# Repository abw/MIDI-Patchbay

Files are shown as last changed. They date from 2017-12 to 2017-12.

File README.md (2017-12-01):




# MIDI-Patchbay
This project contains hardware and firmware for a 4x4 MIDI
merger/splitter patchbay based on an Arduino MEGA 2560.
It has 4 MIDI inputs and 4 MIDI outputs.  In the
simplest case, it will merge all 4 inputs and then split the combined
MIDI stream across the 4 outputs.  However the routing is controlled by
the firmware so you can configure it to patch any combination of inputs
into any of the outputs.

# Table of contents
* [Hardware](#hardware)
* [Firmware](#firmware)
* [Warning](#warning)

## Hardware:

The [hardware](hardware)
directory contains Eagle schematics, board designs and Gerber files for
the following modules.

* [MIDI-Patchbay-Shield](hardware/MIDI-Patchbay-Shield)
is a shield for an Arduino MEGA 2560 that provides 4 MIDI inputs, 4 MIDI
outputs and connectors for interfacing to the
[MIDI-Patchbay-Display](hardware/MIDI-Patchbay-Display)
board.  It also contains connectors for accessing 8 analog pins and 8
digital pins for further expansion.  This is the main board that you
need to build.

* [MIDI-Patchbay-Display](hardware/MIDI-Patchbay-Display)
is a board for mounting a 16x2 LCD display and two RGB rotary encoders.
This is an optional extra.  You can build a fully functioning MIDI
merger/splitter without it.

* [MIDI-Patchbay-Simple](hardware/MIDI-Patchbay-Simple)
is the predecessor of the [MIDI-Patchbay-Shield](hardware/MIDI-Patchbay-Shield).
This is a reduced size shield for the Arduino MEGA 2560 that only has 4
MIDI inputs and 4 MIDI outputs, along with the relevant circuitry to
support it.  If you just want a simple MIDI merger/splitter without any
extra frills then this is the simplest option as an *alternative* to the
above.

The boards use surface mount (SMD) components, but nothing smaller than
0805 (that's 2012 in metric: approximately 2.0mm x 1.25mm) which can easily
be soldered by hand.  It's really not much harder than through-hole
components, so don't be put off if you haven't used SMD before.  But you
will need to invest in some tweezers and a magnifier/light unit to help
you see what you're doing.  And of course, a decent soldering iron.

## Firmware:

The [firmware](firmware)
directory contains the source code for the firmware that powers the
boards listed above.  It is built around the Arduino [MIDI Library](https://github.com/FortySevenEffects/arduino_midi_library)
by [Forty Seven Effects](https://github.com/FortySevenEffects).

* [MIDI-Patchbay-Simple.ino](firmware/MIDI-Patchbay-Simple.ino) implements
a simple 4x4 MIDI patchbay that merges all four MIDI inputs and duplicates
them across all four MIDI outputs.  It is specifically for use with the
basic [MIDI-Patchbay-Simple](hardware/MIDI-Patchbay-Simple) board, but
can also be used with the more advanced [MIDI-Patchbay-Shield](hardware/MIDI-Patchbay-Shield)
if you just need simple functionality.  Or you can use this as a starting
point for your own implementation of the firmware.

## Warning:

These are new designs that haven't been fully tested yet.  Use them at
your own risk.

## Author

Andy Wardley <abw@wardley.org> December 2017

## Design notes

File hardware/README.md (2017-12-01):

# Hardware

This directory contains the schematics and circuit board layouts for

* [MIDI-Patchbay-Shield](MIDI-Patchbay-Shield) adds MIDI IN/OUT
functionality to an Arduino MEGA 2560, along with connectors for
the optional [MIDI-Patchbay-Display](MIDI-Patchbay-Display) and
access to digital and analog pins for adding further switches,
potentiometers, etc.

* [MIDI-Patchbay-Display](MIDI-Patchbay-Display) is an optional extra
for mounting an LCD display and rotary encoders.  This is used in
conjunction with the [MIDI-Patchbay-Shield](MIDI-Patchbay-Shield).

* [MIDI-Patchbay-Simple](MIDI-Patchbay-Simple) is the predecessor to
[MIDI-Patchbay-Shield](MIDI-Patchbay-Shield).  It's an older and slightly
simpler version (e.g. no support for displays or rotary encoders), so
good if you just want a basic MIDI merger/splitter unit, or perhaps
something to adapt for your own project.

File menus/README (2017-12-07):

This directory is being used to develop and test a menu system for the LCD.

It uses a regular desktop development environment rather than targetting 
the Arduino.  This makes developing, testing and debugging considerably
easier. 

When it's nearing completion the code will be moved/merged into the 
formware/MIDI-Patchbay directory.

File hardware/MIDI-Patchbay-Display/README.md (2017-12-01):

# MIDI-Patchbay-Display

This directory contains the schematic and board layout for a daughter
board for mounting a 16x2 LCD display and 2 [RGB rotary encoders](https://www.sparkfun.com/products/10982).

This is an optional extra that can be used in conjunction with the
[MIDI-Patchbay-Shield](../MIDI-Patchbay-Shield)
or with your own projects that require an LCD display and/or encoders.

A 10 pin (2x5) IDC connector is used to connect to the LCD.  A 16 pin
(2x8) IDC connector is used to connect to the rotary encoders.

The board contains the "anti-chatter" circuits on the rotaty encoders that
are recommended in the [data sheet](https://cdn.sparkfun.com/datasheets/Components/Switches/EC12PLRGBSDVBF-D-25K-24-24C-6108-6HSPEC.pdf).
It also has a pull-down resistor, current limiting resistor and debounce
capacitor on the push switches for each encoder.

The RGB LEDs in the encoders, and the LED in the backlight of the LCD,
are all switched through transistors with the appropriate
current-limiting resistors in series.  The intensity of the LEDs can
be changed using Pulse Width Modulation (PWM) directly from Arduino
pins.  The transistors are used so that we're not powering the LEDs
directly from the Arduino pins and don't have to worry about exceeding
any of the current source/sink limits of the microprocessor.

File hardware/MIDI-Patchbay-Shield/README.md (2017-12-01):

# MIDI-Patchbay-Shield

This directory contains the schematic and board layout for the MIDI
Patchbay shield for the Arduino MEGA 2560.

This is the main circuit board that you need for the project.

It has connectors for 4 MIDI inputs and 4 MIDI outputs.

It has LCD and ENCODER connectors which you can use to connect it to the
[MIDI-Patchbay-Display](../MIDI-Patchbay-Display)
board.  This is an optional extra for attaching an LCD display and one or
two rotary encoders.  This allows you to monitor MIDI traffic, program and
select patches to change the MIDI routing, and generally interface with
the MIDI Patchbay.  It's not required if you just want to build a simple,
static MIDI merger/splitter.

Is has further DIGITAL and ANALOG connectors which give you easy
access to 8 digital pins and 8 analog pins.  You can use these for
expanding the project, e.g. to add push buttons or potentiometers.

There's also a PEDAL connector.  This is wired in parallel with MIDI
INPUT 1 but has an additional pin providing VIN voltage.  This is used
to connect to another project of mine, the MIDI Foot Pedal Controller
(coming to github soon).  You can ignore this for now.

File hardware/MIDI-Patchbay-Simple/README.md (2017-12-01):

# MIDI-Patchbay-Simple

This directory contains the schematic and board layout for the
predecessor/prototype of the [MIDI Patchbay Shield](../MIDI-Patchbay-Shield) for the Arduino MEGA 2560.

This is a simple 4 MIDI IN / 4 MIDI OUT merger and splitter.

The [MIDI Patchbay Shield](../MIDI-Patchbay-Shield)
is the newer design with more functionality, but if you want something
simple and slightly easier/cheaper/quicker to build then this might be
the droids you're looking for.

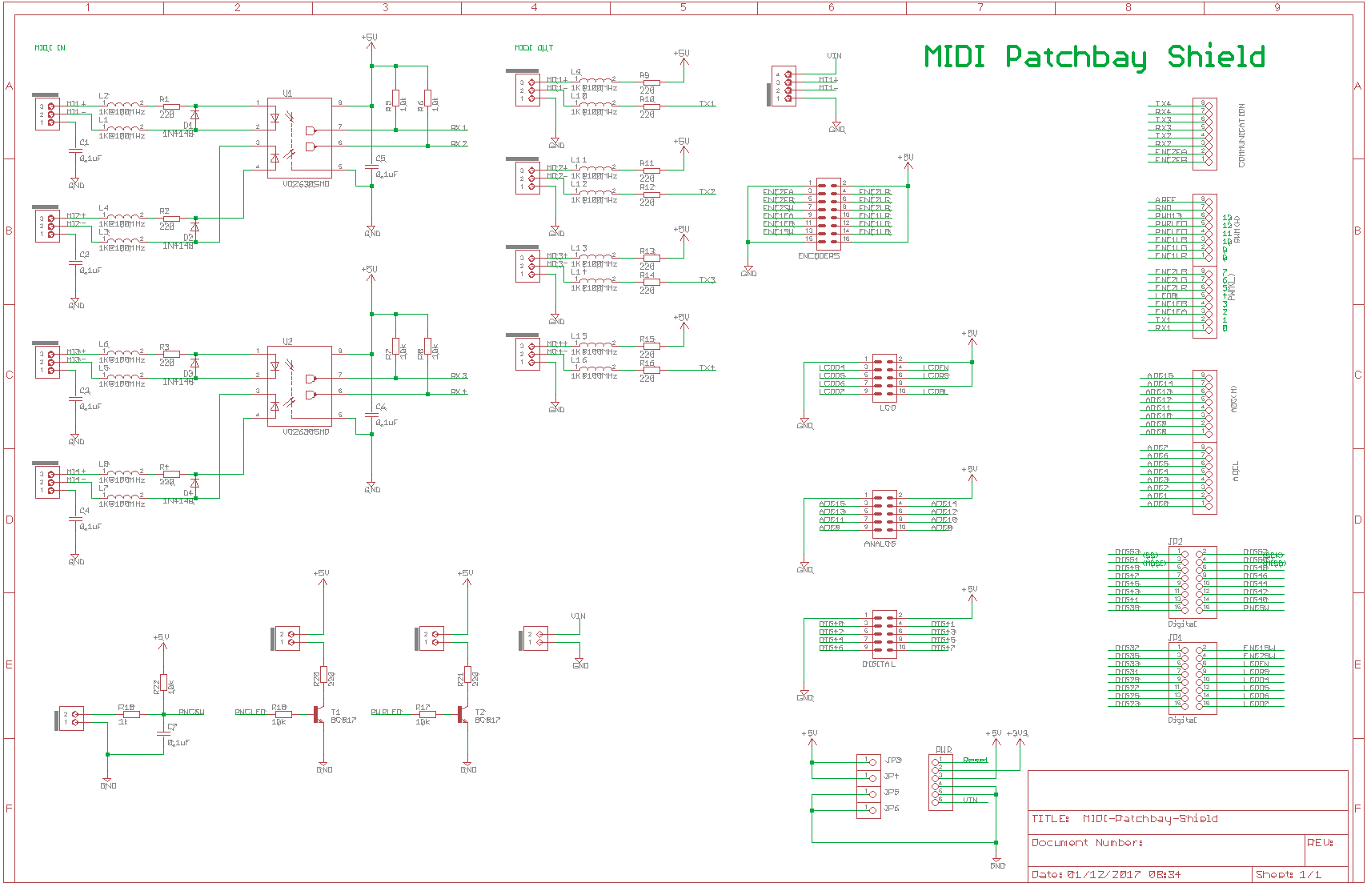
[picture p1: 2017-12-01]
hardware/MIDI-Patchbay-Shield/schematic.gif

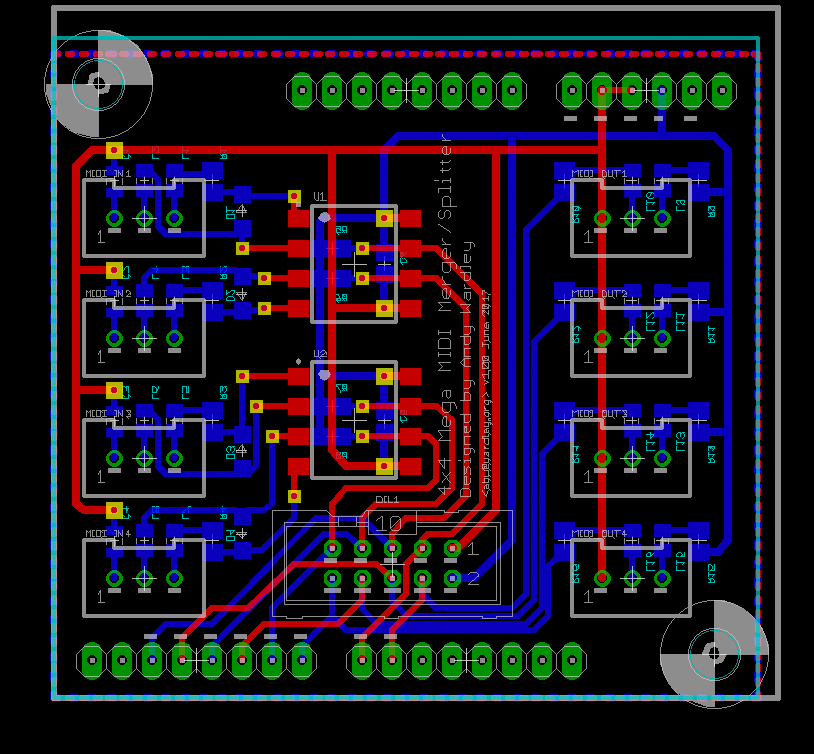
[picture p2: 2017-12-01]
hardware/MIDI-Patchbay-Simple/board.gif

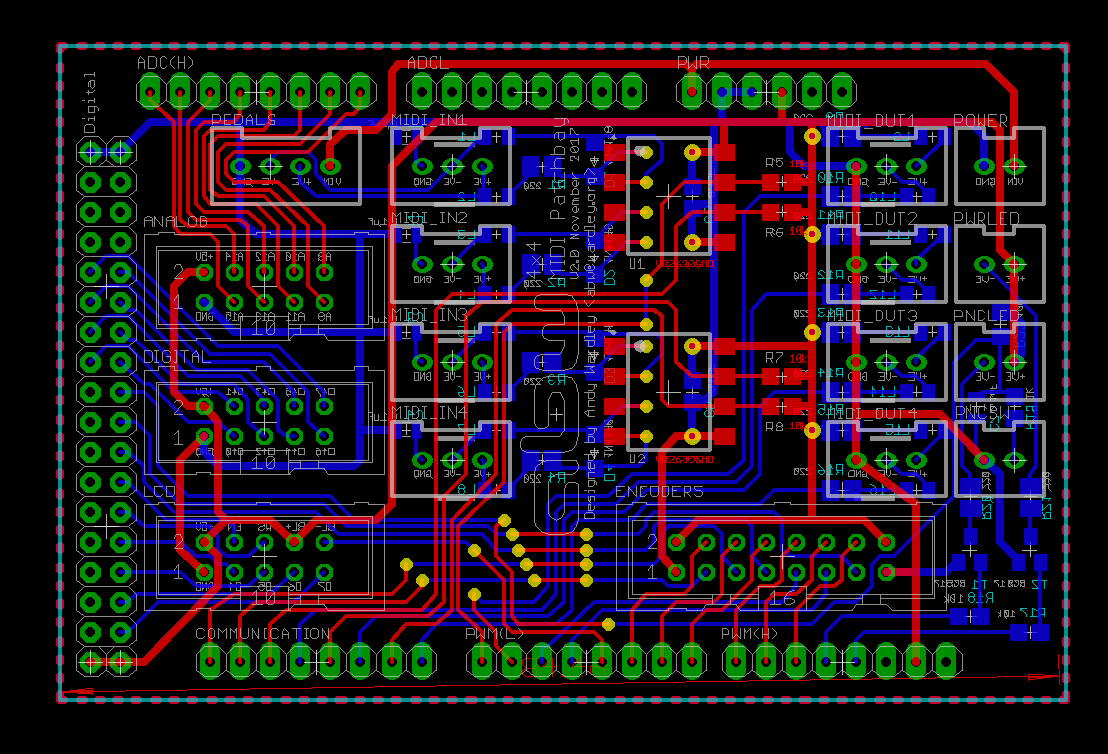
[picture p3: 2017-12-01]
hardware/MIDI-Patchbay-Shield/board.gif

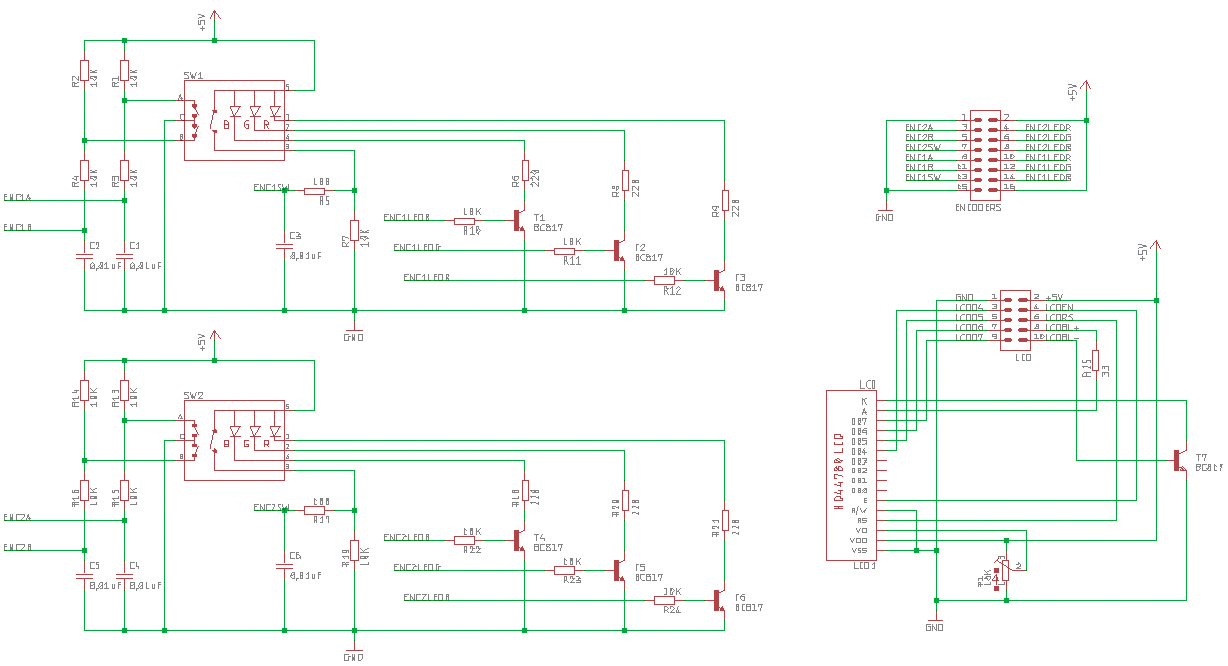
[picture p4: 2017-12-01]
hardware/MIDI-Patchbay-Display/schematic.gif

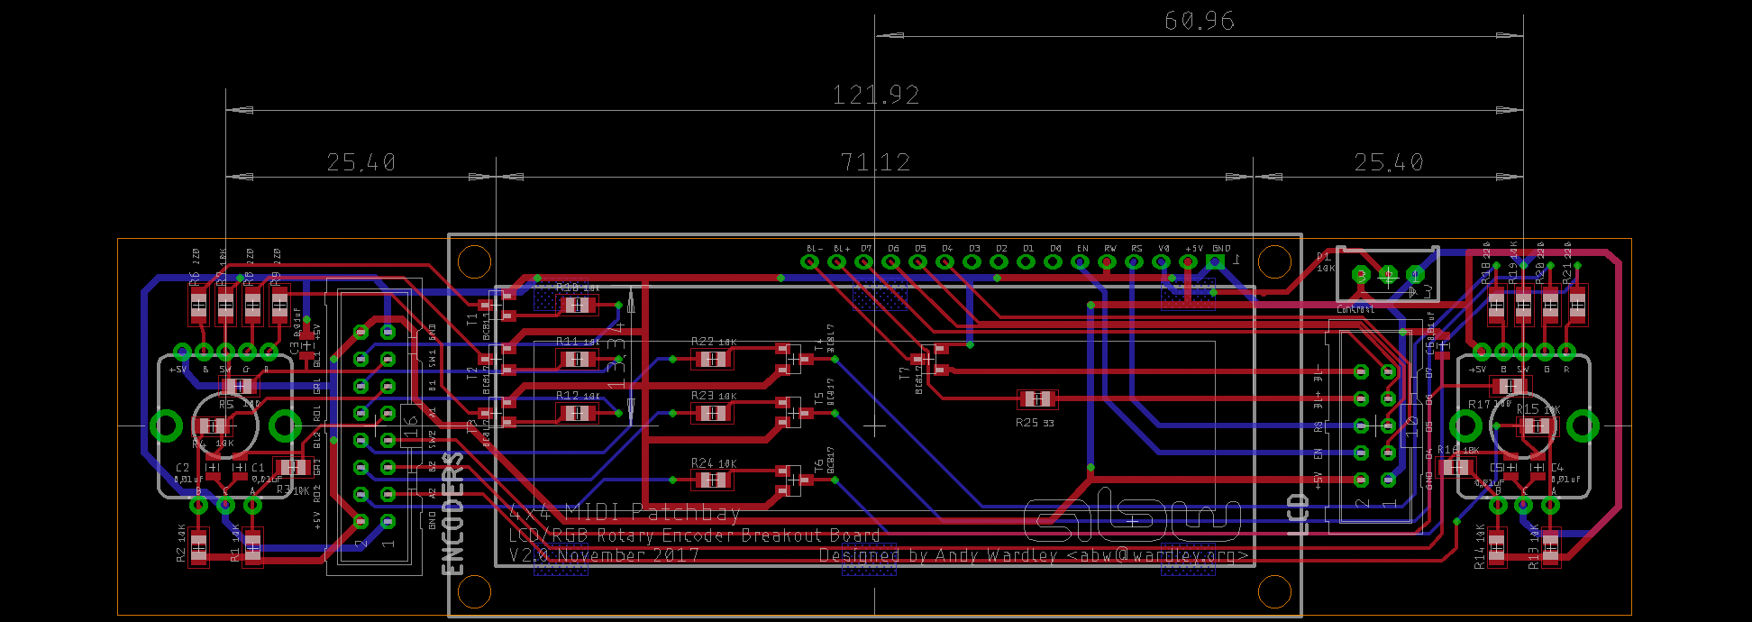
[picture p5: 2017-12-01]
hardware/MIDI-Patchbay-Display/board.gif

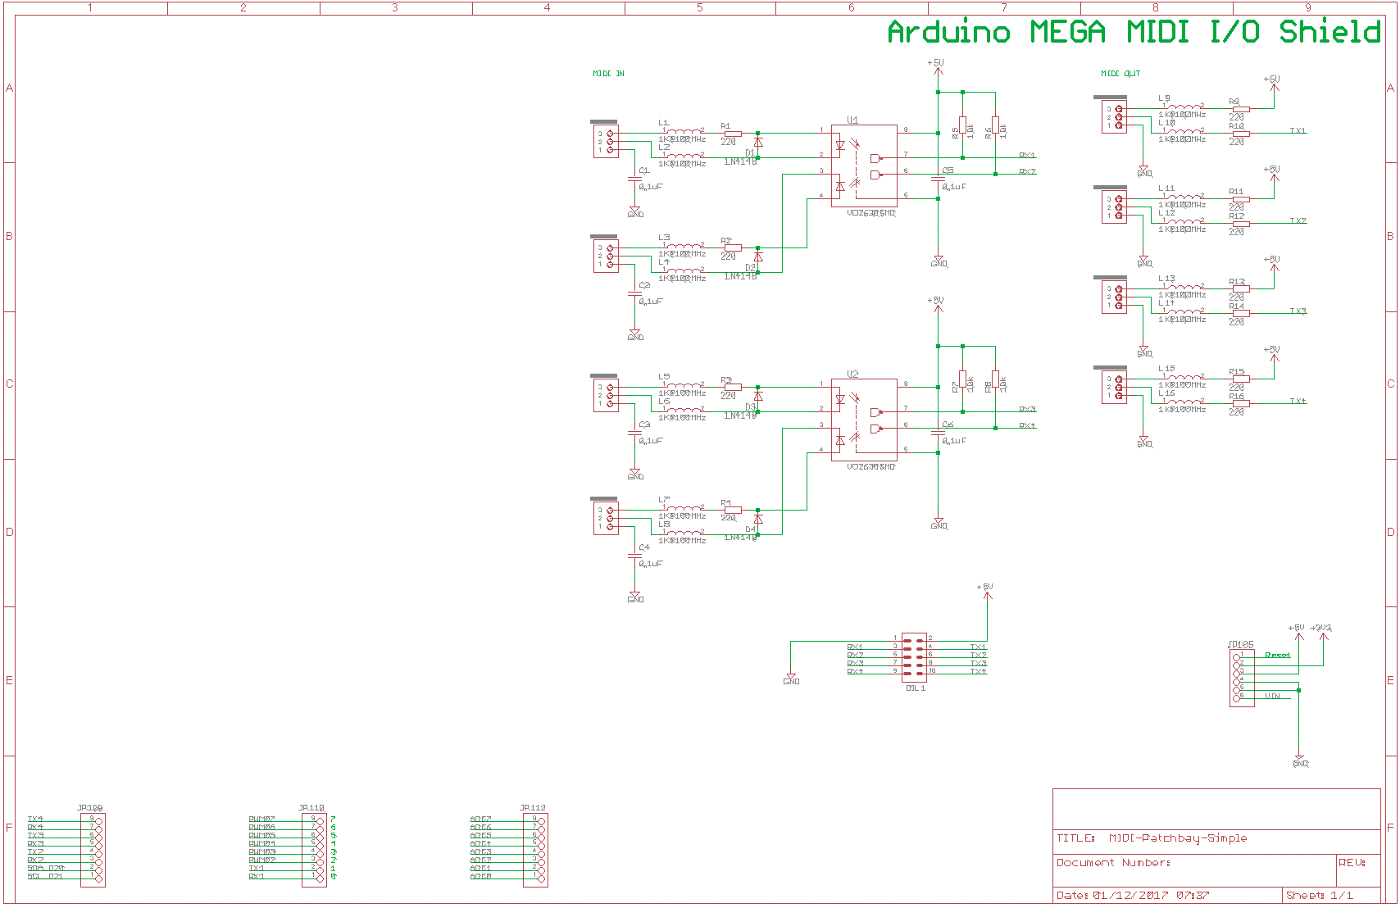
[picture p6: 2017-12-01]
hardware/MIDI-Patchbay-Simple/schematic.gif

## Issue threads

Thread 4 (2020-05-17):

Compatibility PCF8574?

Cysign, 2020-05-17:
Hi,
which files would I need to configure to get an HD44780 running on i2c?

Also a new layout for Arduino2560 Pro mini would be nice, since we don't need so much space for the Arduino board ;)

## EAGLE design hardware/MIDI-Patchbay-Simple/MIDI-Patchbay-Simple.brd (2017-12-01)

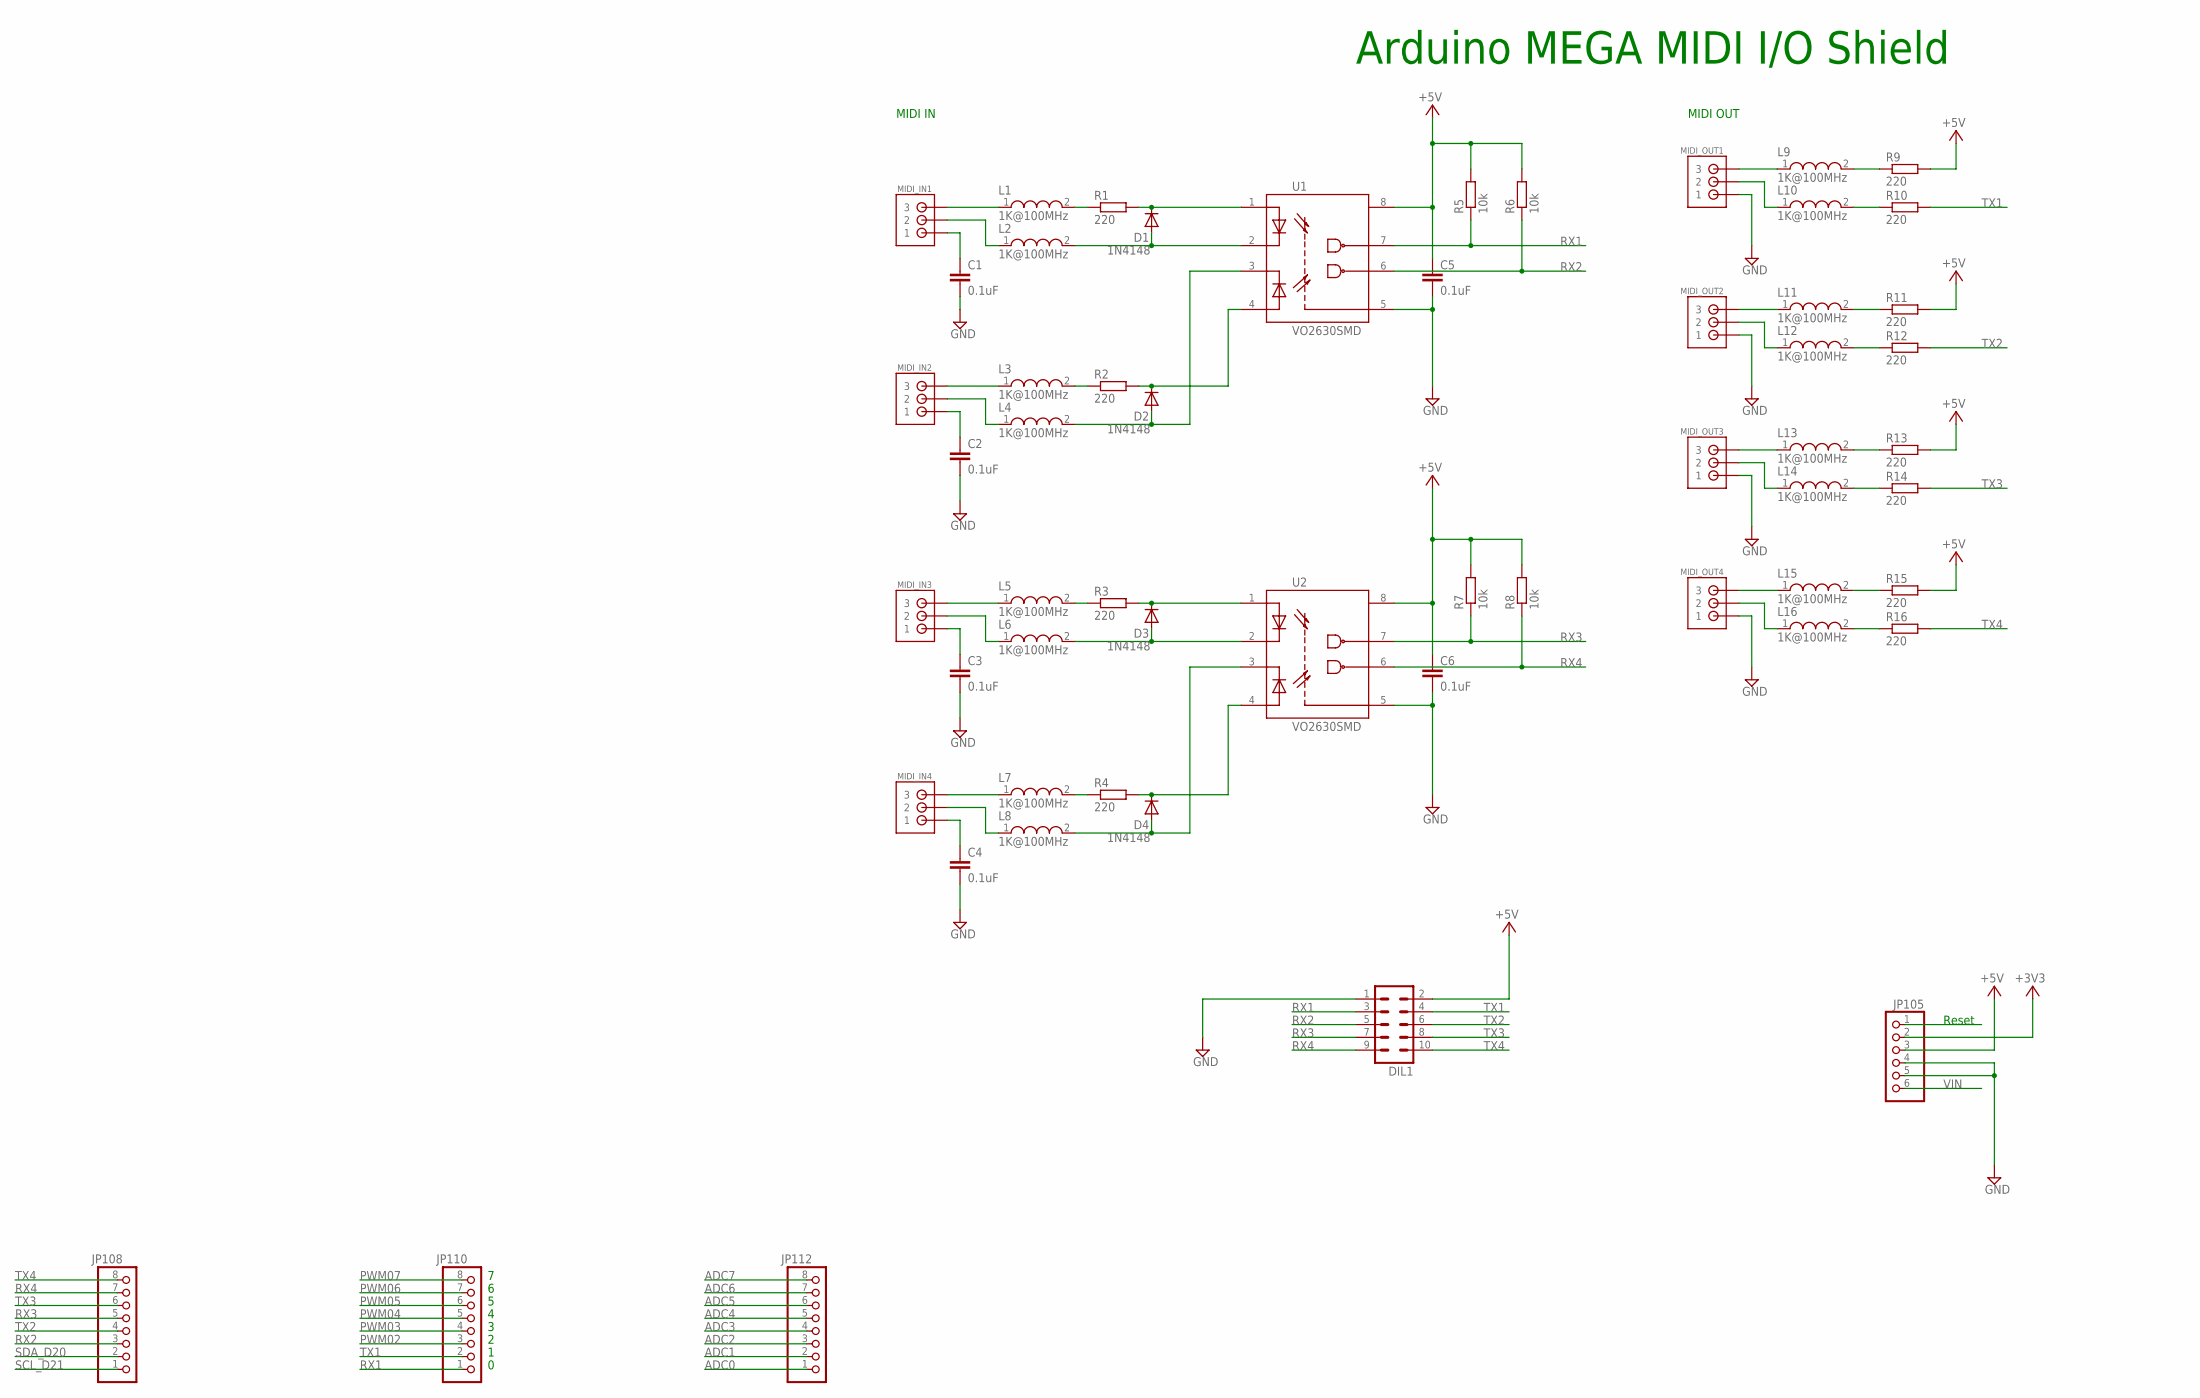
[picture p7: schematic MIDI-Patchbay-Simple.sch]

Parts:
C1, C2, C3, C4: 0.1uF; 0805
C5, C6: 0.1uF; C0805
D1, D2, D3, D4: 1N4148; SOD323-W
DIL1: ML10
JP105: PINHD-1X6; 1X06
JP108, JP110, JP112: PINHD-1X8; 1X08
L1, L2, L3, L4, L5, L6, L7, L8, L9, L10, L11, L12, L13, L14, L15, L16: 1K@100MHz; WE-RFI_0805
MIDI_IN1, MIDI_IN2, MIDI_IN3, MIDI_IN4: JST-XA-03-PIN; JST-XA-03
MIDI_OUT1, MIDI_OUT2, MIDI_OUT3, MIDI_OUT4: JST-XA-03-PIN; JST-XA-03
R1, R2, R3, R4, R9, R10, R11, R12, R13, R14, R15, R16: 220; M0805
R5, R6, R7, R8: 10k; R0805
U1, U2: VO2630SMD; SOIC254P1030X390-8N

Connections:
+3V3: JP105.2
+5V: C5.1, C6.1, DIL1.2, JP105.3, R5.2, R6.2, R7.2, R8.2, R9.2, R11.2, R13.2, R15.2, U1.8 (VCC), U2.8 (VCC)
ADC0: JP112.1
ADC1: JP112.2
ADC2: JP112.3
ADC3: JP112.4
ADC4: JP112.5
ADC5: JP112.6
ADC6: JP112.7
ADC7: JP112.8
GND: C1.2, C2.2, C3.2, C4.2, C5.2, C6.2, DIL1.1, JP105.4, JP105.5, MIDI_OUT1.1, MIDI_OUT2.1, MIDI_OUT3.1, MIDI_OUT4.1, U1.5 (GND), U2.5 (GND)
IC1: D1.C, R1.2, U1.1 (A1)
IC2: D2.C, R2.2, U1.4 (A2)
IC3: D3.C, R3.2, U2.1 (A1)
IC4: D4.C, R4.2, U2.4 (A2)
unnamed: L1.1, MIDI_IN1.3
unnamed: L2.1, MIDI_IN1.2
unnamed: C1.1, MIDI_IN1.1
unnamed: L1.2, R1.1
unnamed: L9.1, MIDI_OUT1.3
unnamed: D1.A, L2.2, U1.2 (C1)
unnamed: L10.1, MIDI_OUT1.2
unnamed: L9.2, R9.1
unnamed: L10.2, R10.1
unnamed: L3.1, MIDI_IN2.3
unnamed: L4.1, MIDI_IN2.2
unnamed: L3.2, R2.1
unnamed: D2.A, L4.2, U1.3 (C2)
unnamed: C2.1, MIDI_IN2.1
unnamed: L5.1, MIDI_IN3.3
unnamed: L6.1, MIDI_IN3.2
unnamed: L5.2, R3.1
unnamed: D3.A, L6.2, U2.2 (C1)
unnamed: C3.1, MIDI_IN3.1
unnamed: L7.1, MIDI_IN4.3
unnamed: L8.1, MIDI_IN4.2
unnamed: L7.2, R4.1
unnamed: D4.A, L8.2, U2.3 (C2)
unnamed: C4.1, MIDI_IN4.1
unnamed: L11.1, MIDI_OUT2.3
unnamed: L12.1, MIDI_OUT2.2
unnamed: L11.2, R11.1
unnamed: L12.2, R12.1
unnamed: L13.1, MIDI_OUT3.3
unnamed: L14.1, MIDI_OUT3.2
unnamed: L13.2, R13.1
unnamed: L14.2, R14.1
unnamed: L15.1, MIDI_OUT4.3
unnamed: L16.1, MIDI_OUT4.2
unnamed: L15.2, R15.1
unnamed: L16.2, R16.1
PWM02: JP110.3
PWM03: JP110.4
PWM04: JP110.5
PWM05: JP110.6
PWM06: JP110.7
PWM07: JP110.8
RESET: JP105.1
RX1: DIL1.3, JP110.1, R5.1, U1.7 (VO1)
RX2: DIL1.5, JP108.3, R6.1, U1.6 (VO2)
RX3: DIL1.7, JP108.5, R7.1, U2.7 (VO1)
RX4: DIL1.9, JP108.7, R8.1, U2.6 (VO2)
SCL_D21: JP108.1
SDA_D20: JP108.2
TX1: DIL1.4, JP110.2, R10.2
TX2: DIL1.6, JP108.4, R12.2
TX3: DIL1.8, JP108.6, R14.2
TX4: DIL1.10, JP108.8, R16.2
VIN: JP105.6

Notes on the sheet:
Arduino MEGA MIDI I/O Shield
Reset
MIDI IN
MIDI OUT

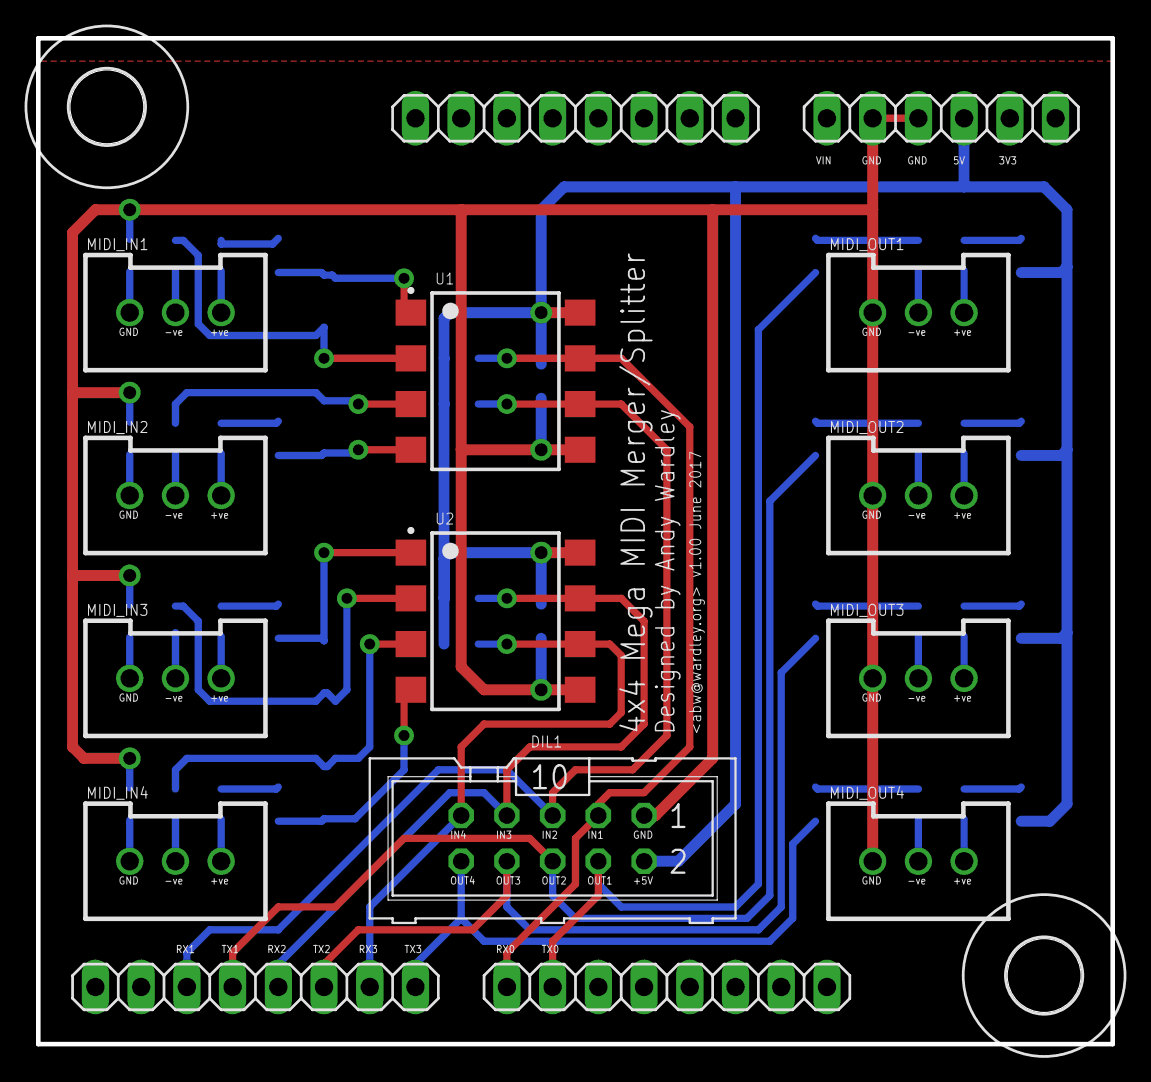
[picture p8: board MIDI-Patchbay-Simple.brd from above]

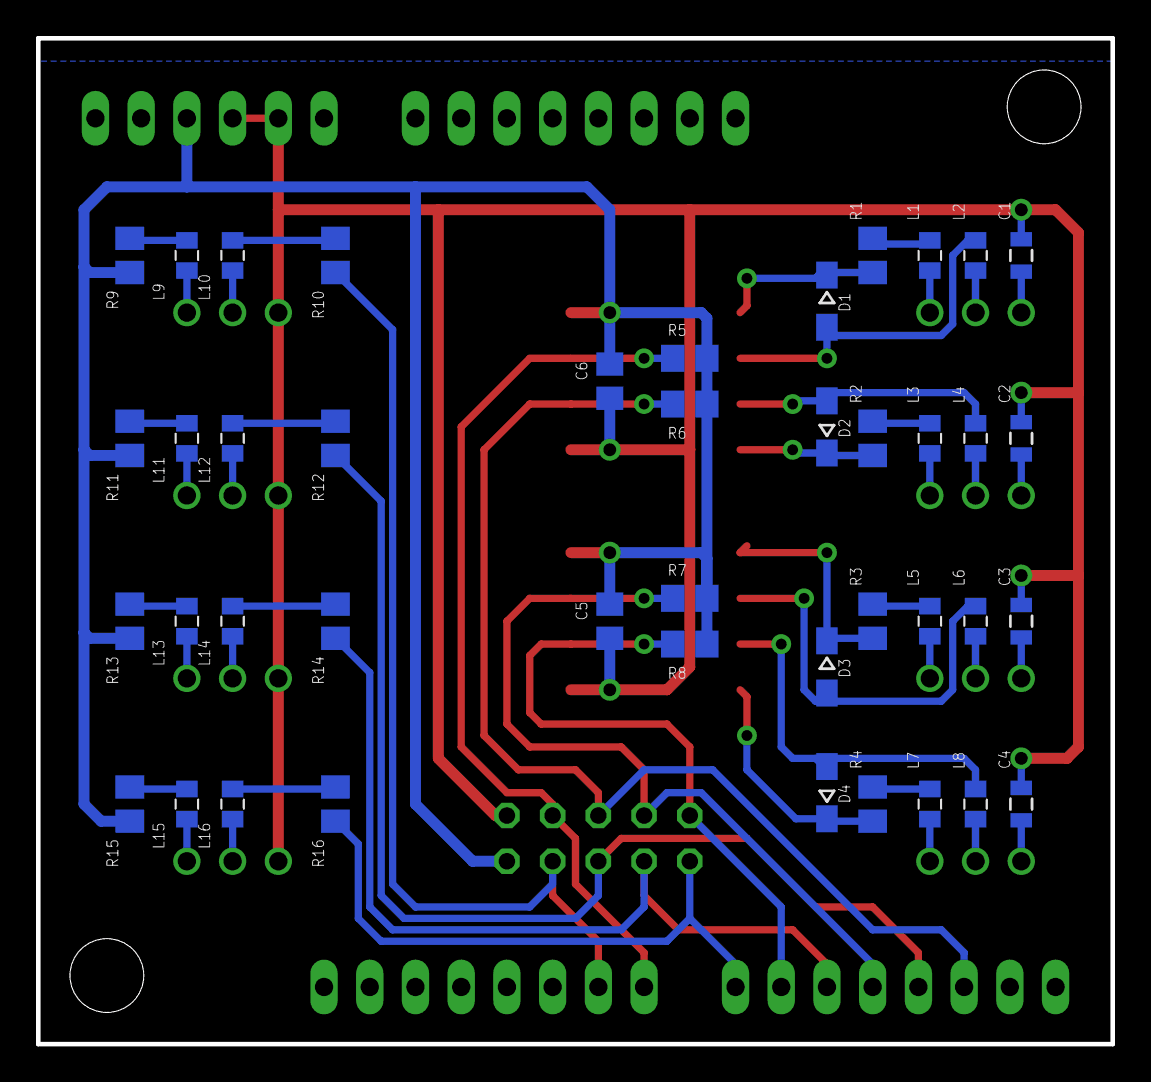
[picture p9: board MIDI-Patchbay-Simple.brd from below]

Board: 2 copper layers, 59.7 x 55.9 mm, 59 parts (42 on the bottom side), 50 nets.

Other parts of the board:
U$1, U$2: 4,1

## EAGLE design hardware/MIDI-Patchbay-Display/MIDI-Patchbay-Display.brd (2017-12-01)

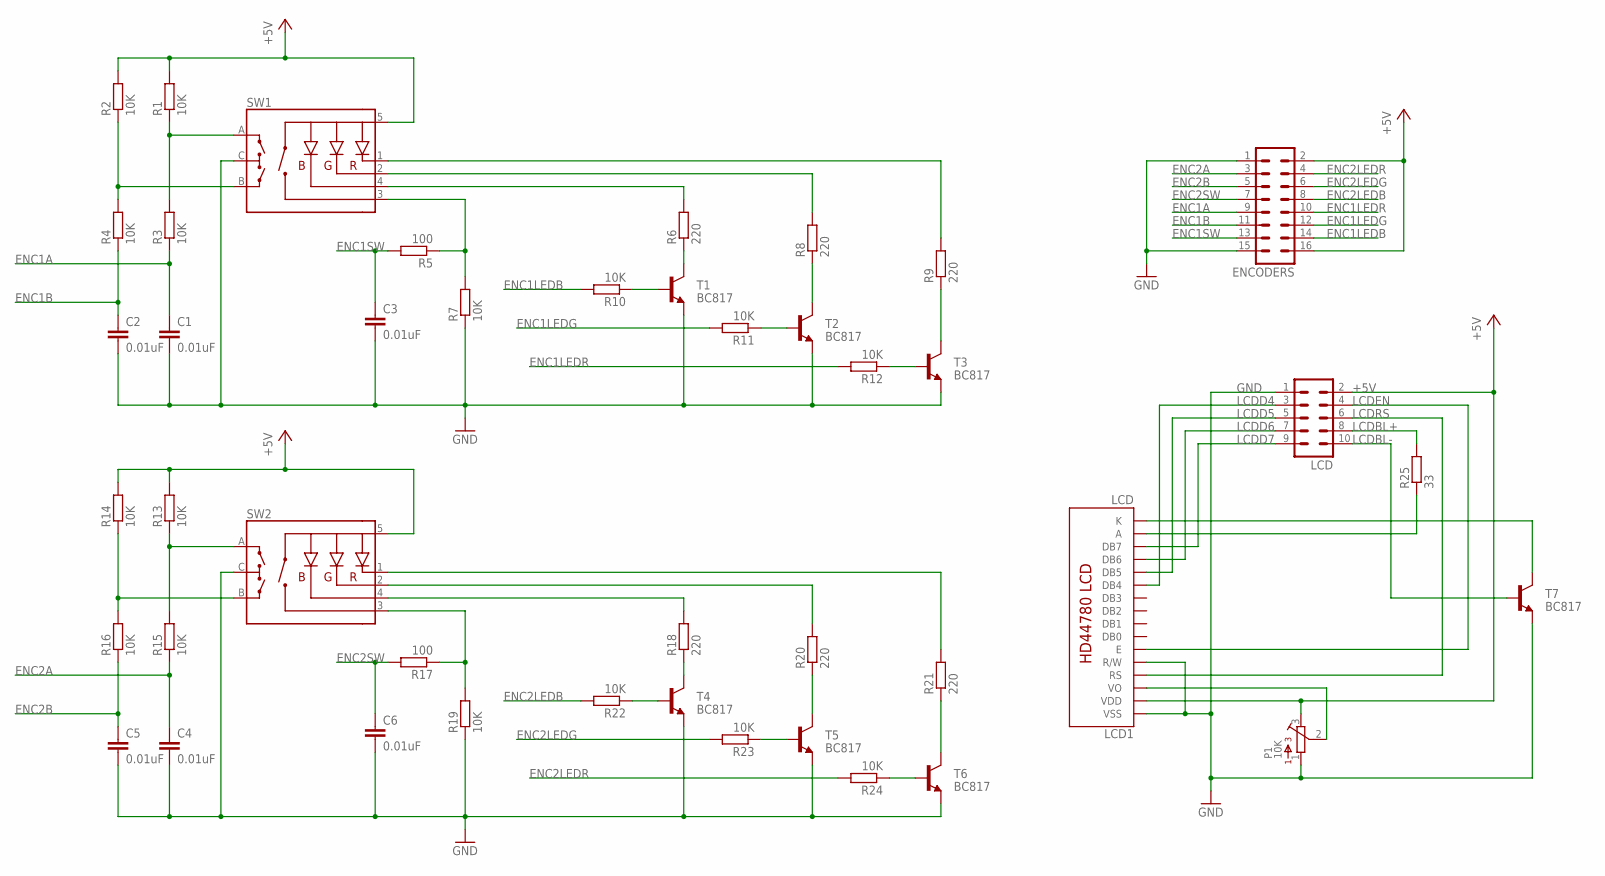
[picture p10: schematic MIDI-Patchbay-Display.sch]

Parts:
C1, C2, C3, C4, C5, C6: 0.01uF; 0805
ENCODERS: ML16
LCD: ML10
LCD1: LCD; LCD-16X2-4HOLES
P1: 10K; 3386W
R1, R2, R3, R4, R7, R10, R11, R12, R13, R14, R15, R16, R19, R22, R23, R24: 10K; R0805
R5, R17: 100; R0805
R6, R8, R9, R18, R20, R21: 220; R0805
R25: 33; R0805
SW1, SW2: ENCODER_RGB_CA; ENCODER_LED_3
T1, T2, T3, T4, T5, T6, T7: BC817; SOT23

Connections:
+5V: ENCODERS.2, ENCODERS.16, LCD.2, LCD1.2 (VDD), P1.3, R1.2, R2.2, R13.2, R14.2, SW1.5 (+), SW2.5 (+)
ENC1A: C1.1, ENCODERS.9, R3.1
ENC1APIN: R1.1, R3.2, SW1.A
ENC1B: C2.1, ENCODERS.11, R4.1
ENC1BPIN: R2.1, R4.2, SW1.B
ENC1LEDB: ENCODERS.14, R10.2
ENC1LEDG: ENCODERS.12, R11.2
ENC1LEDR: ENCODERS.10, R12.2
ENC1SW: C3.1, ENCODERS.13, R5.2
ENC2A: C4.1, ENCODERS.3, R15.1
ENC2APIN: R13.1, R15.2, SW2.A
ENC2B: C5.1, ENCODERS.5, R16.1
ENC2BPIN: R14.1, R16.2, SW2.B
ENC2LEDB: ENCODERS.8, R22.2
ENC2LEDG: ENCODERS.6, R23.2
ENC2LEDR: ENCODERS.4, R24.2
ENC2SW: C6.1, ENCODERS.7, R17.2
GND: C1.2, C2.2, C3.2, C4.2, C5.2, C6.2, ENCODERS.1, ENCODERS.15, LCD.1, LCD1.1 (VSS), LCD1.5 (R/W), P1.1, R7.1, R19.1, SW1.C, SW2.C, T1.2 (E), T2.2 (E), T3.2 (E), T4.2 (E), T5.2 (E), T6.2 (E), T7.2 (E)
LCDA: LCD1.15 (A), R25.1
LCDBL+: LCD.8, R25.2
LCDBL-: LCD.10, T7.1 (B)
LCDD4: LCD.3, LCD1.11 (DB4)
LCDD5: LCD.5, LCD1.12 (DB5)
LCDD6: LCD.7, LCD1.13 (DB6)
LCDD7: LCD.9, LCD1.14 (DB7)
LCDEN: LCD.4, LCD1.6 (E)
LCDK: LCD1.16 (K), T7.3 (C)
LCDRS: LCD.6, LCD1.4 (RS)
unnamed: R6.1, T1.3 (C)
unnamed: R6.2, SW1.4 (-B)
unnamed: LCD1.3 (VO), P1.2
unnamed: R8.1, T2.3 (C)
unnamed: R10.1, T1.1 (B)
unnamed: R11.1, T2.1 (B)
unnamed: R8.2, SW1.2 (-G)
unnamed: R9.1, T3.3 (C)
unnamed: R12.1, T3.1 (B)
unnamed: R9.2, SW1.1 (-R)
unnamed: R5.1, R7.2, SW1.3 (SW)
unnamed: R18.2, SW2.4 (-B)
unnamed: R18.1, T4.3 (C)
unnamed: R22.1, T4.1 (B)
unnamed: R20.1, T5.3 (C)
unnamed: R23.1, T5.1 (B)
unnamed: R20.2, SW2.2 (-G)
unnamed: R21.1, T6.3 (C)
unnamed: R24.1, T6.1 (B)
unnamed: R21.2, SW2.1 (-R)
unnamed: R17.1, R19.2, SW2.3 (SW)

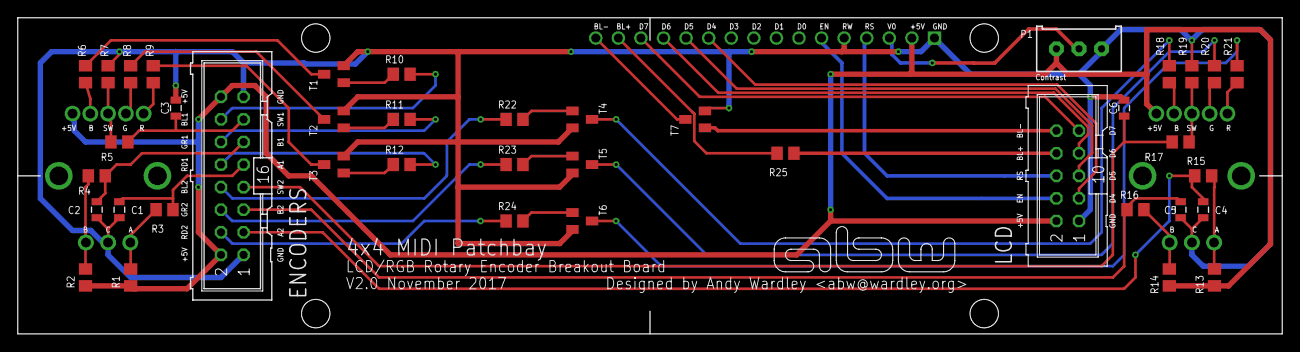
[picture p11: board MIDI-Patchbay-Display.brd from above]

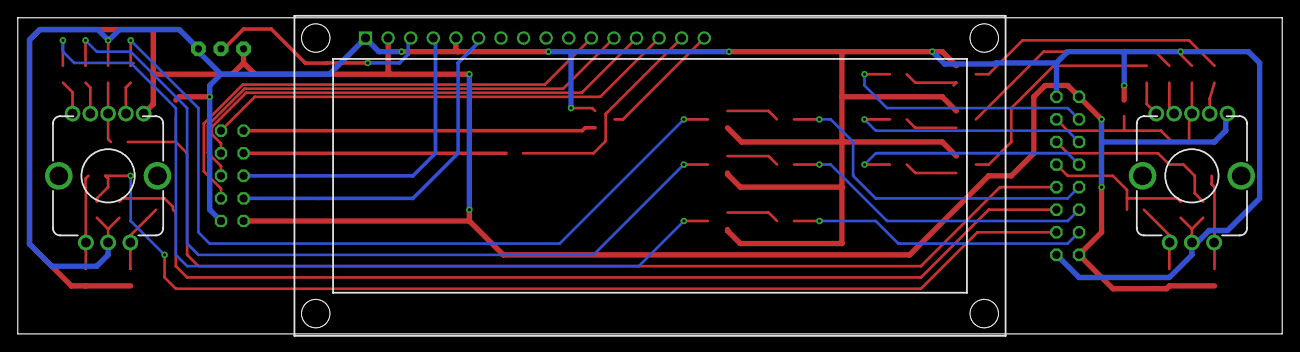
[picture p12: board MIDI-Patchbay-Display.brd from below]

Board: 2 copper layers, 142.2 x 35.6 mm, 45 parts (3 on the bottom side), 49 nets.

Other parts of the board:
U$1: ABWLOGO-MICRO

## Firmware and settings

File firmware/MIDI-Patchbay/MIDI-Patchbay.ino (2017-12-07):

//---------------------------------------------------------------------
// MIDI-Patchbay.ino
//
// Arduino Mega2560 firmware for 4x4 MIDI patchbay.
//
// Written by Andy Wardley <abw@wardley.org> November 2017
//---------------------------------------------------------------------

#include <MIDI.h>
#include <LiquidCrystal.h>
#include <Encoder.h>
#include "MIDI-Patchbay.h"
#include "Config.hpp"
#include "Menus.hpp"
#include "LCD.hpp"
#include "LED.hpp"
#include "Knob.hpp"
#include "Menu.hpp"
#include "MenuItem.hpp"
#include "Patch.hpp"

bool panicButtonPressed();
void MIDISendTo(
    midi::MidiInterface<HardwareSerial> from,
    midi::MidiInterface<HardwareSerial> to
);
void MIDISendToAll(
    midi::MidiInterface<HardwareSerial> from
);

void displayMenu();
void displayMenuItem();
void changeMenuItem(Knob *knob);
void changeMenu(Knob *knob);
void selectMenu(Knob *knob);
void unselectMenu(Knob *knob);

// Arduino Mega 2560 has 4 hardware serial ports for MIDI to use
MIDI_CREATE_INSTANCE(HardwareSerial, Serial,  midiA);
MIDI_CREATE_INSTANCE(HardwareSerial, Serial1, midiB);
MIDI_CREATE_INSTANCE(HardwareSerial, Serial2, midiC);
MIDI_CREATE_INSTANCE(HardwareSerial, Serial3, midiD);

// initialise LCD
LiquidCrystal lcd(
    LCD_RS_PIN, LCD_EN_PIN,
    LCD_D4_PIN, LCD_D5_PIN, LCD_D6_PIN, LCD_D7_PIN
);

// Encoders
Encoder Enc1(ENC1EA_PIN, ENC1EB_PIN);
Encoder Enc2(ENC2EA_PIN, ENC2EB_PIN);

// Encoder 1 is on the left of the PCB and encoder 2 is on the right.
// When viewed from the front we end up with encoder 1 on the right and
// 2 on the left.
Knob leftKnob(
    ENC2SW_PIN, ENC2LR_PIN, ENC2LG_PIN, ENC2LB_PIN,
    &Enc2
);

Knob rightKnob(
    ENC1SW_PIN, ENC1LR_PIN, ENC1LG_PIN, ENC1LB_PIN,
    &Enc1
);

bool patchSelect = 0;

//---------------------------------------------------------------------
// Setup
//---------------------------------------------------------------------

void setup() {
    // setup power and panic pins
    pinMode(POWER_LED_PIN, OUTPUT);
    pinMode(PANIC_LED_PIN, OUTPUT);
    pinMode(PANIC_SW_PIN, INPUT);


    Serial.begin(9600);
    Serial.println("Debugging MIDI Patchbay");

    initLCD(&lcd);

    // listen to all MIDI channels on all 4 inputs
    //midiA.begin(MIDI_CHANNEL_OMNI);
    //midiB.begin(MIDI_CHANNEL_OMNI);
    //midiC.begin(MIDI_CHANNEL_OMNI);
    //midiD.begin(MIDI_CHANNEL_OMNI);

    //// disable automatic THRU handling
    //midiA.turnThruOff();
    //midiB.turnThruOff();
    //midiC.turnThruOff();
    //midiD.turnThruOff();

    // start the clock
    start = millis();

    loadConfig();

    leftKnob.onChange(&changeMenu);
    leftKnob.onPress(&selectMenu);
    leftKnob.onHold(&unselectMenu);
    rightKnob.onChange(&changeMenuItem);
}

//---------------------------------------------------------------------
// loop
//---------------------------------------------------------------------

void loop() {
    int activity = 0;
    unsigned long now = millis(), ticks = now - start;

    // check all four MIDI inputs for data and send to all MIDI outputs
    if (midiA.read()) {
        MIDISendToAll(midiA);
    }
    if (midiB.read()) {
        MIDISendToAll(midiB);
    }
    if (midiC.read()) {
        MIDISendToAll(midiC);
    }
    if (midiD.read()) {
        MIDISendToAll(midiD);
    }

    // read encoders, pulse the LEDs if they're not being used
    if (! leftKnob.read()) {
        pulseEncLeft(now);
    }
    if (! rightKnob.read()) {
        pulseEncRight(now);
    }

    // TODO: monitor MIDI and send to LCD / Encoder LEDs

    // check panic button
    if (panicButtonPressed()) {
        if (panicSent) {
            // fade out LED
            fadePanic(now - panicSent);
            pulsePower(now);
        }
        else {
            if (panicStarted) {
                if (now - panicStarted > panicDelay) {
                    //MIDIPanic();
                    panicSent = now;
                }
            }
            else {
                panicStarted = now;
            }
            flashPanic(now);
            flashPower(now);
        }
    }
    else {
        panicStarted = panicSent = 0;
        pulsePanic(now);
        pulsePower(now);
    }
}

bool panicButtonPressed() {
    return digitalRead(PANIC_SW_PIN) == 0;
}

//---------------------------------------------------------------------
// Knob functions
//---------------------------------------------------------------------

void showMenus() {
    menuOn = 1;
    menuIn = 0;
    menu   = menus[menuIndex];
    patchSelect = 0;
    leftKnob.setRange(0, menuMax);
    leftKnob.setValue(menuIndex);
    initLCDMenuCharset(&lcd);
    displayMenuName();
}

void hideMenus() {
    menuOn = 0;
    menuIn = 0;
    welcomeScreen(&lcd);
}

void displayMenu() {
    menu->attach(&lcd, &leftKnob, &rightKnob);
    menu->display();
}

void displayMenuName() {
    menu->attach(&lcd, &leftKnob, &rightKnob);
    menu->displayName();
}

void displayPatch() {
    lcd.clear();
    lcd.setCursor(0, 0);
    lcd.print("Patch ");
    lcd.setCursor(6, 0);
    lcd.print(patchIndex + 1);
    lcd.setCursor(0, 1);
    lcd.print(patch.getName());
}

void selectMenu(Knob *knob) {
    if (menuOn && ! menuIn) {
        patchSelect = 0;
        menuIn = 1;
        displayMenu();
    }
    else {
        showMenus();
    }
}

void changeMenu(Knob *knob) {
    //Serial.println("TODO: changeMenu()");
    if (menuIn) {
        menu->change(knob->getValue());
    }
    else if (menuOn) {
        menuIndex = knob->getValue();
        menuIndex = menuIndex < 0 ? 0 : menuIndex > menuMax ? menuMax : menuIndex;
        menu = menus[menuIndex];
        displayMenuName();
    }
    else {
        showMenus();
    }
}


void unselectMenu(Knob *knob) {
    hideMenus();
}

void changeMenuItem(Knob *knob) {
    if (menuOn && menuIn) {
        menu->changeItem(knob->getValue());
    }
    else if (patchSelect) {
        patchIndex = knob->getValue();
        patchIndex = patchIndex < 0 ? 0 : patchIndex > patchMax ? patchMax : patchIndex;
        patch = patches[patchIndex];
        displayPatch();
    }
    else {
        patchSelect = 1;
        // program knob
        rightKnob.setRange(0, patchMax);
        rightKnob.setValue(patchIndex);
        displayPatch();
    }
}

//---------------------------------------------------------------------
// MIDI functions
//---------------------------------------------------------------------

void MIDISendTo(
    midi::MidiInterface<HardwareSerial> from,
    midi::MidiInterface<HardwareSerial> to
) {
    // duplicate message on <from> input to <to> output
    to.send(
        from.getType(),
        from.getData1(),
        from.getData2(),
        from.getChannel()
    );
}

void MIDISendToAll(
    midi::MidiInterface<HardwareSerial> from
) {
    // duplicate message (except ActiveSensing) on <from> to all MIDI outputs
    midi::MidiType type = from.getType();
    if (type != midi::ActiveSensing) {
        MIDISendTo(from, midiA);
        MIDISendTo(from, midiB);
        MIDISendTo(from, midiC);
        MIDISendTo(from, midiD);
    }
}

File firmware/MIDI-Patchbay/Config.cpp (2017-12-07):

#include "Config.hpp"
#include "LED.hpp"

unsigned long
    start        = 0,
    panicSent    = 0,
    panicStarted = 0;

unsigned int
    // LCD
    lcdBrightness       = LCD_BRIGHTNESS,
    // left encoder
    encLeftHue          = ENCL_HUE,
    encLeftSaturation   = ENC_SATURATION,
    encLeftWaveform     = ENC_WAVEFORM,
    encLeftFrequency    = ENC_FREQUENCY,
    encLeftPhase        = ENC_PHASE,
    encLeftMin          = ENC_MIN,
    encLeftMax          = ENC_MAX,
    // right encoder
    encRightHue         = ENCR_HUE,
    encRightSaturation  = ENC_SATURATION,
    encRightWaveform    = ENC_WAVEFORM,
    encRightFrequency   = ENC_FREQUENCY,
    encRightPhase       = ENC_PHASE,
    encRightMin         = ENC_MIN,
    encRightMax         = ENC_MAX,
    //panic button
    panicPulseWaveform  = PULSE_WAVEFORM,
    panicPulseFrequency = PULSE_FREQUENCY,
    panicPulsePhase     = PULSE_PHASE,
    panicPulseMin       = PULSE_MIN,
    panicPulseMax       = PULSE_MAX,
    panicFlashWaveform  = FLASH_WAVEFORM,
    panicFlashFrequency = FLASH_FREQUENCY,
    panicFlashPhase     = FLASH_PHASE,
    panicFlashMin       = FLASH_MIN,
    panicFlashMax       = FLASH_MAX,
    panicDelay          = PANIC_DELAY,
    panicFade           = PANIC_FADE,
    // power button
    powerPulseWaveform  = PULSE_WAVEFORM,
    powerPulseFrequency = PULSE_FREQUENCY,
    powerPulsePhase     = PULSE_PHASE,
    powerPulseMin       = PULSE_MIN,
    powerPulseMax       = PULSE_MAX,
    powerFlashWaveform  = FLASH_WAVEFORM,
    powerFlashFrequency = FLASH_FREQUENCY,
    powerFlashPhase     = FLASH_PHASE,
    powerFlashMin       = FLASH_MIN,
    powerFlashMax       = FLASH_MAX;

Oscillator oscillators[] = {
    &normalSin,
    &normalSquare,
    &normalSawUp,
    &normalSawDown
};

Oscillator powerPulseOscillator = &normalSin;
Oscillator powerFlashOscillator = &normalSquare;
Oscillator panicPulseOscillator = &normalSin;
Oscillator panicFlashOscillator = &normalSquare;
Oscillator encLeftOscillator    = &normalSin;
Oscillator encRightOscillator   = &normalSin;



//---------------------------------------------------------------------
// Config setters
//---------------------------------------------------------------------

void setLCDBacklightBrightness(int value) {
    lcdBrightness = value;
    analogWrite(LCD_BL_PIN, value);
}

void setPowerPulseWaveform(int value) {
    powerPulseWaveform   = value;
    powerPulseOscillator = oscillators[value];
}

void setPowerFlashWaveform(int value) {
    powerFlashWaveform   = value;
    powerFlashOscillator = oscillators[value];
}

void setPanicPulseWaveform(int value) {
    panicPulseWaveform   = value;
    panicPulseOscillator = oscillators[value];
}

void setPanicFlashWaveform(int value) {
    panicFlashWaveform   = value;
    panicFlashOscillator = oscillators[value];
}

void setEncLeftWaveform(int value) {
    encLeftWaveform   = value;
    encLeftOscillator = oscillators[value];
}

void setEncRightWaveform(int value) {
    encRightWaveform   = value;
    encRightOscillator = oscillators[value];
}

void setPowerPulseFrequency(int value)  { powerPulseFrequency   = value; }
void setPowerPulsePhase(int value)      { powerPulsePhase       = value; }
void setPowerPulseMin(int value)        { powerPulseMin         = value; }
void setPowerPulseMax(int value)        { powerPulseMax         = value; }

void setPowerFlashFrequency(int value)  { powerFlashFrequency   = value; }
void setPowerFlashPhase(int value)      { powerFlashPhase       = value; }
void setPowerFlashMin(int value)        { powerFlashMin         = value; }
void setPowerFlashMax(int value)        { powerFlashMax         = value; }

void setPanicPulseFrequency(int value)  { panicPulseFrequency   = value; }
void setPanicPulsePhase(int value)      { panicPulsePhase       = value; }
void setPanicPulseMin(int value)        { panicPulseMin         = value; }
void setPanicPulseMax(int value)        { panicPulseMax         = value; }

void setPanicFlashFrequency(int value)  { panicFlashFrequency   = value; }
void setPanicFlashPhase(int value)      { panicFlashPhase       = value; }
void setPanicFlashMin(int value)        { panicFlashMin         = value; }
void setPanicFlashMax(int value)        { panicFlashMax         = value; }

void setPanicDelay(int value)           { panicDelay            = value; }
void setPanicFade(int value)            { panicFade             = value; }

void setEncLeftHue(int value)           { encLeftHue            = value; }
void setEncLeftSaturation(int value)    { encLeftSaturation     = value; }
void setEncLeftFrequency(int value)     { encLeftFrequency      = value; }
void setEncLeftPhase(int value)         { encLeftPhase          = value; }
void setEncLeftMin(int value)           { encLeftMin            = value; }
void setEncLeftMax(int value)           { encLeftMax            = value; }
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

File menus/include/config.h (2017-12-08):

#ifndef CONFIG_H
#define CONFIG_H

// default configuration values
#define LCD_BRIGHTNESS  200

// encoders
#define ENCL_HUE        210
#define ENCR_HUE        270
#define ENC_SATURATION  255
#define ENC_WAVEFORM      0
#define ENC_FREQUENCY     4
#define ENC_PHASE         0
#define ENC_MIN          24
#define ENC_MAX         128

// slow pulse for panic/power buttons
#define PULSE_WAVEFORM    0
#define PULSE_FREQUENCY   4
#define PULSE_PHASE       0
#define PULSE_MIN         6
#define PULSE_MAX        64

// faster flash for panic/power buttons
#define FLASH_WAVEFORM    1
#define FLASH_FREQUENCY  15
#define FLASH_PHASE       0
#define FLASH_MIN         0
#define FLASH_MAX       255

// panic button options
#define PANIC_DELAY    1000
#define PANIC_FADE     1000

// patch options
#define PATCH_NAME_SIZE 16
#define UNTITLED_PATCH   "<untitled>"

#define N_PATCHES       16
#define N_FREQUENCIES   21
#define N_WAVEFORMS      4
#define MAX_PATCH       (N_PATCHES - 1)
#define MAX_FREQUENCY   (N_FREQUENCIES - 1)
#define MAX_WAVEFORM    (N_WAVEFORMS - 1)

#define MAX_PHASE       359
#define MAX_VAL         255
#define MAX_HUE         359
#define MAX_SATURATION  255
#define MAX_BRIGHTNESS  255
#define MAX_TIMER      9999


#endif /* CONFIG_H */

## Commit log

2017-12-01 Added hardware designs and updated README
    [MIDI-Patchbay-Display.brd, MIDI-Patchbay-Display.sch, MIDI-Patchbay-Shield.brd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]
2017-12-01 Added MIDI-Patchbay-Simple
    [MIDI-Patchbay-Simple.brd, MIDI-Patchbay-Simple.sch]
2017-12-01 Added images for boards and schematics
    [MIDI-Patchbay-Shield.sch]
2017-12-01 Added gerber files
2017-12-01 Added new tests for LCD, encoders and panic/power switch LEDs
2017-12-07 Added oscillators and start of patches
    [config.h]
2017-12-08 Replaced C++ classes with smaller, simpler C functions and structs
    [config.h, patchbay.c]

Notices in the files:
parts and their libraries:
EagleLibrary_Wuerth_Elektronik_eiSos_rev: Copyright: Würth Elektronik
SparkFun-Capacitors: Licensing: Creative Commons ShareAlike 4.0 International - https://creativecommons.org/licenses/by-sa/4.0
